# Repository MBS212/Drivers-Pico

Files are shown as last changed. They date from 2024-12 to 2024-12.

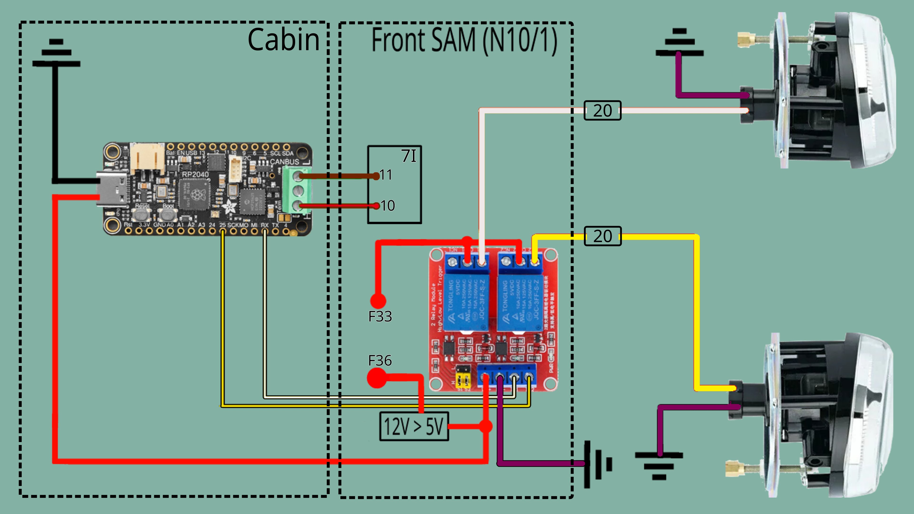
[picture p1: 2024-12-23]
Images/Electrical-diagram.jpg

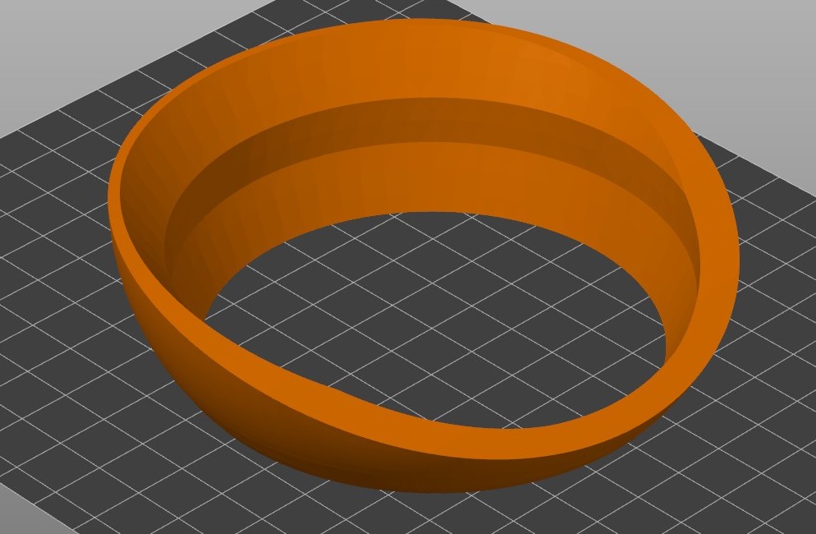
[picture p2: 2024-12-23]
Images/light-unit-bezel.jpg

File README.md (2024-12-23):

This is the repo for fitting Adafurit RP2040 CAN bus Feather to Mercedes-Benz W/S 212 vehicles as additional controller and plugging it into the vehicle's CAN bus B, to interract with other control units.

Currently implemented the following functions:
  1. Fitting custom cornering lights to Mercedes-Benz vehicle, model S212 by aquiring CAN bus messges. The code was created in Arduino IDE. The CAN bus IDs used in this project so far:
     1. Steering Angle Sensor;
     2. Light Sensor;
     3. Turn Indicator switch msgs;
     4. Vehicle Speed Sensors;
     5. Vehicle's Headlight Sensor.

For the full explanation see the following YouTube videos:
1. Video 1 - short demo, needed hardware, and sniffing thrugh the CAN bus frames: https://youtu.be/QOX_SNWhKeo
2. Video 2 - Analizing the Arduino Code: https://youtu.be/sk0XZvBpJHA
3. Video 3 - Installing of the hardware: https://youtu.be/rINvdyTEydw

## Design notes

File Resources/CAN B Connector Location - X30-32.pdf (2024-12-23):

Document title | Location of electrical connectors - Left front footwell
Document number | gf0019p100512dda

# 1005-12DDA Location of electrical connectors - Left front GF00.19-Pfootwell

# Model 213 as of model year 2021

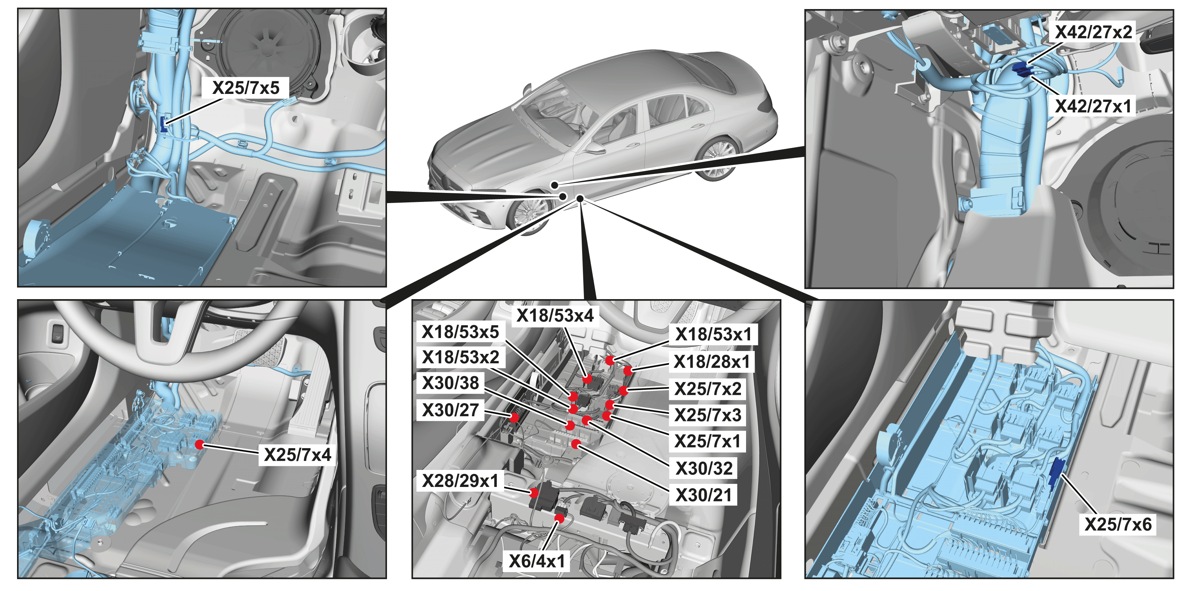
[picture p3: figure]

P54.18-A138-79

© Mercedes-Benz AG, 2/27/23, L/10/20, gf00.19-p-1005-12dda, Location of electrical connectors - Left front footwell | Page 1 of 1
Model 213 as of model year 2021

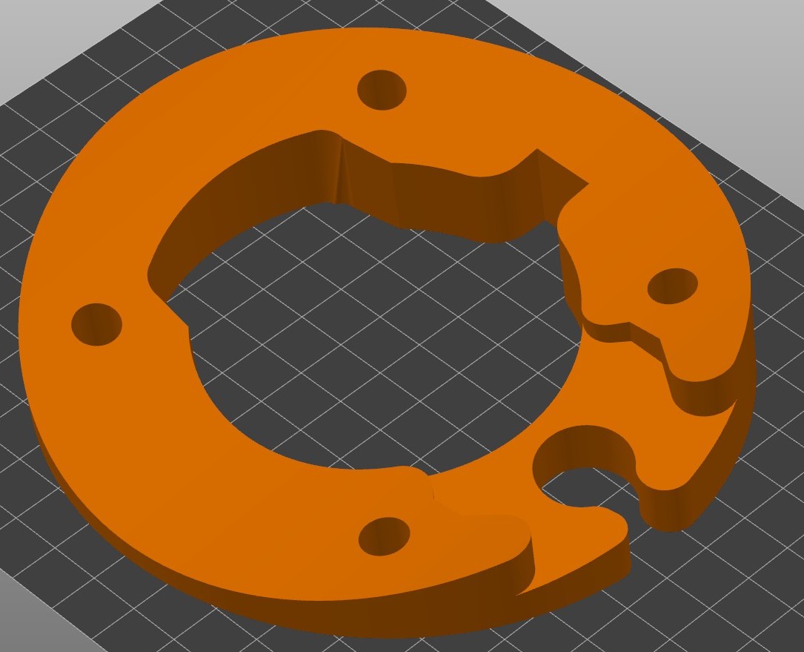
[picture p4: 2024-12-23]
Images/light-unit-bracket(flange)-rear-Right.jpg

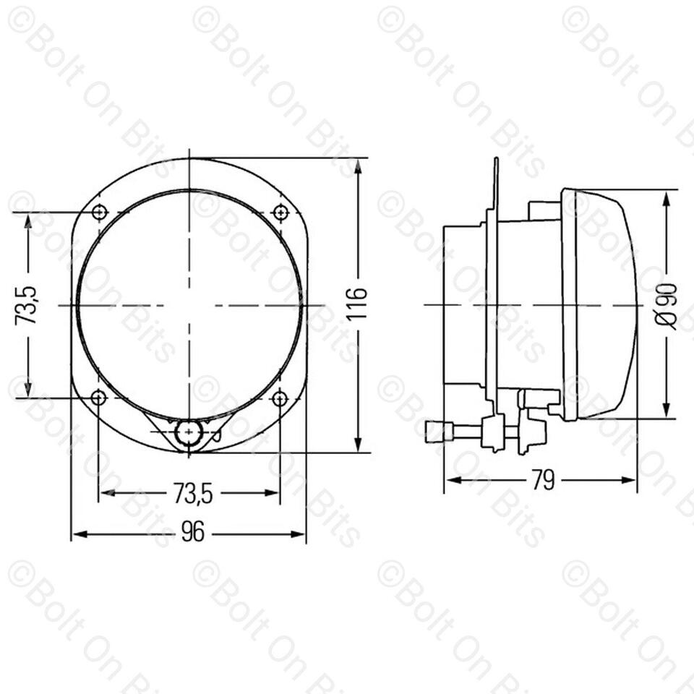
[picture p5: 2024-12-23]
Images/merc-cornering-lights-dimensions.jpg

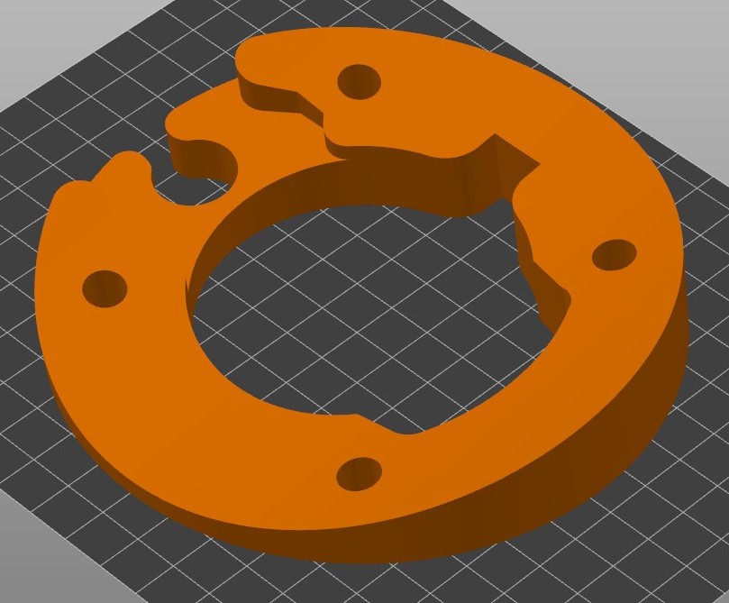
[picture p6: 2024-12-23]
Images/light-unit-bracket(flange)-rear-Left.jpg

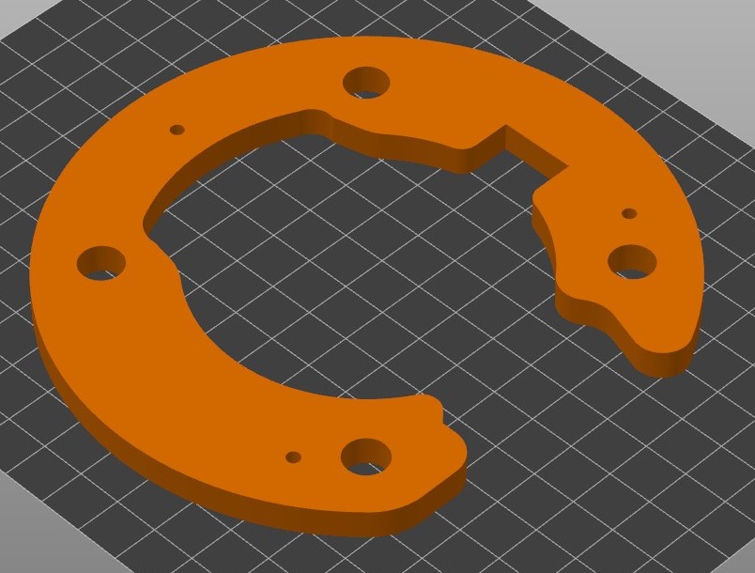
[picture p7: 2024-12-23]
Images/light-unit-bracket-front-L-and-R.jpg

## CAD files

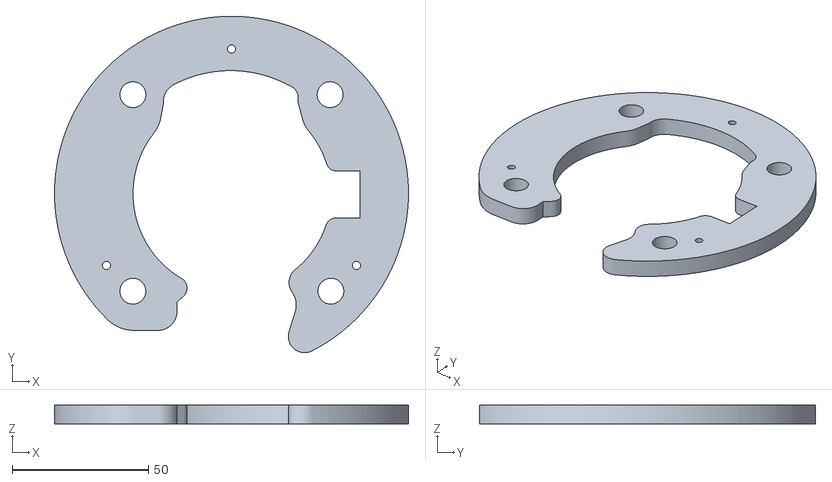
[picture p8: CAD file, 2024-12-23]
STL Files/light-unit-bracket-front-L-and-R.stl
130.0 x 123.5 x 6.82

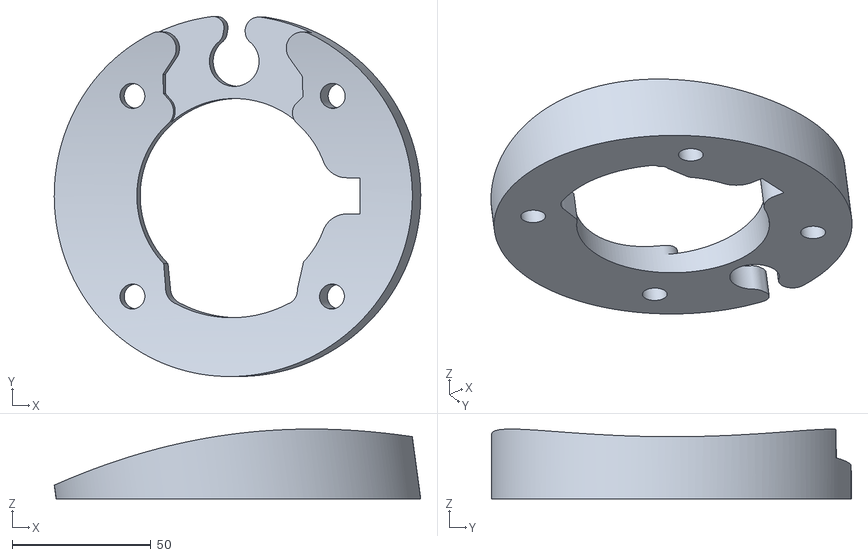
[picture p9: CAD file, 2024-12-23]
STL Files/light-unit-bracket(flange)-rear-Left.stl
131.9 x 129.5 x 25.2

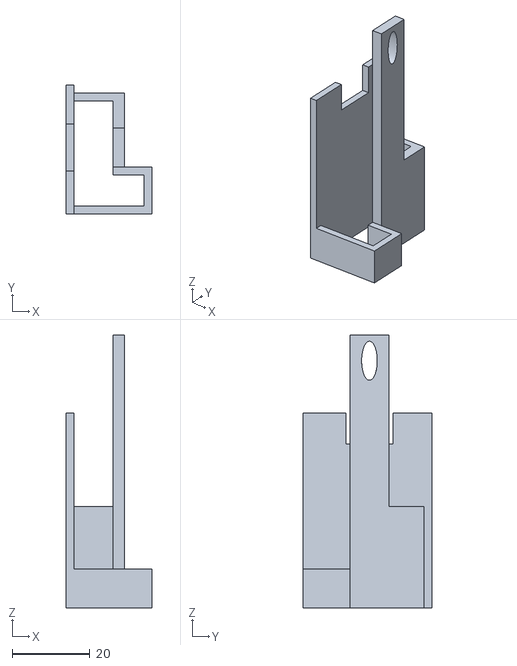
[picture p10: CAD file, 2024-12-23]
STL Files/pico-enclosure.stl
22.0 x 33.0 x 70.0

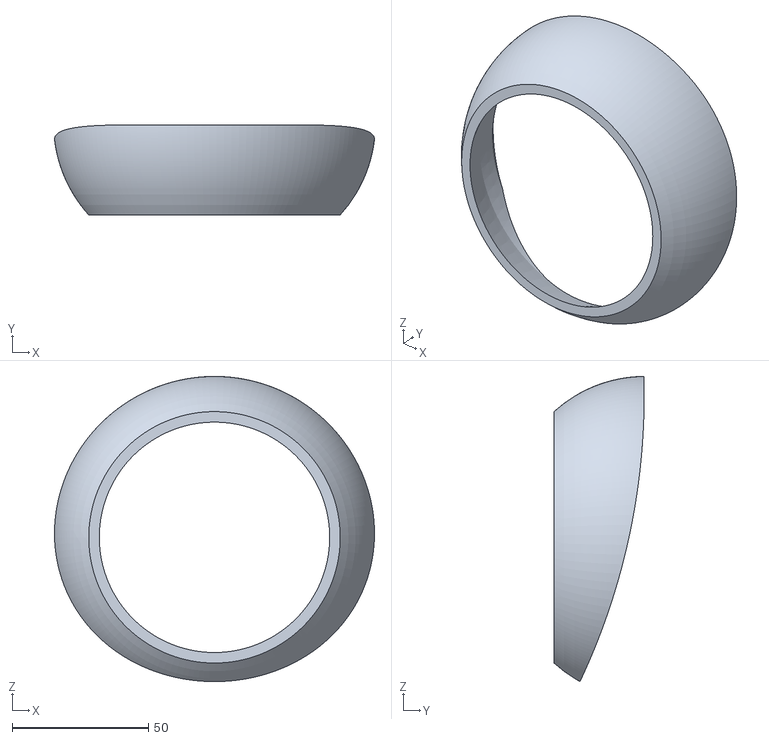
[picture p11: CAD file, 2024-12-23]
STL Files/light-unit-bezel.stl
117.2 x 33.0 x 111.8

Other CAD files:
STL Files/light-unit-bracket(flange)-rear-Right.stl

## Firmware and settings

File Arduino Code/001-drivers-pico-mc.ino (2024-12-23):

// main file of the project to:
// - to switch on/off the custom cornering lights;
// - to move servo with my GoPro camera attached to it;
// based on the Mercedes S212 E300 Hybrid, 
//   the sensor data aquired through the CAN bus frames

#include "canbusreader.h"  // file to process CAN bus messages and get the values
#include "servocontrol.h"  // file to control GoPro servo motor dep. on st. wheel angle
#include "corneringlights.h"  // to control the cornering lights

bool Debug = false;  // onboard neopix is OFF, set to true for debugging

// trying to smooth servo movements with millis()
unsigned long canTime = 0;
unsigned long servoTime = 0;
unsigned long pixelsTime = 0;

void setup()  // rp2040 1st core setup
{
  SetupCan();     // defined in canfunctions.h
  delay(1000);
}

void loop()  // rp2040 1st core loop
{
  // process CAN bus msgs and return the steering wheel angle (value betw. 3100 & 5100)
  // this function is in canbusreader.h
//  if( millis() - canTime >= 5 )
//  {
    ReadCAN();  
//    canTime = millis();
//  }
}

///////////////////////////////////////
void setup1()  // rp2040 2nd core setup
{
  SetupServo();   // defined in servocontrol.h

  SetupCorneringLights();

  // Set the on-board Neopixel pin to output and high
  //   in order to enable the NeoPixels. 
  if( Debug )
  {
    pinMode(NEOPIXEL_POWER, OUTPUT);
    digitalWrite(NEOPIXEL_POWER, HIGH);
    pixels.begin();            // init. NeoPixel object
    pixels.setBrightness(5);  // NeoPixel's brightness
  }
  delay(1000);
}

void loop1()  // rp2040 2nd core loop
{
  // if it's daylight,
  // than move our GoPro's servo depending on
  // the st. wheel angle, 
  // else we don't need to control servo at night
  if( !nightTime )
  {
    if( millis() - servoTime >= 10 )
    {
//      MoveGopro();  // this function is in servocontrol.h
      servoTime = millis();
    }
  }

  // 29.04.2024:
  //   Removed frome here the condition if(nightTime)
  //   because it would create a bug that it will not switch off the lights 
  //   when nightTime changes to false (day time) while we are driving.
  //   This condition is now added in the RunCorneringLights() function.
  RunCorneringLights();

  if( Debug )
  {
    if( millis() - pixelsTime >= 100 )
    {
      pixels.fill(currentPixColor); // set the pix color
      pixels.show();                // light up the pix
      pixelsTime = millis();
    }
  }
}

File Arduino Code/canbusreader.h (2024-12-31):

/* contains functions:
SetupCan()
ReadCan() to read the can bus
          and to process the data
          
updates:
28.12.24 - added reading of the 3rd byte from CAN msg because
           the 3rd byte of turn signal give clear indication
           if left is on, or if right is on;
         - changed turn signal values from 80 and 144 to 5 and 10 from the 3rd byte
           so that the event will trigger not only on touch, but also on switch
         - added gearLeverPos var., in order to switch on both corn. lights 
           not when the vehicle starts moving backward, but when the reverse gear
           is engaged with the gear lever (right side of steer. wheel) 
*/
#include <Adafruit_MCP2515.h>

#define CS_PIN    PIN_CAN_CS
Adafruit_MCP2515 mcp(CS_PIN);  // the CAN bus processing
  
// Set CAN bus baud rate depending on which CAN bus we are connected to
#define CAN_B   125000  // bus B speed: 125 kbps
#define CAN_E   500000  // bus E speed: 500 kbps

// variables related to reading the vehicle's light sensor
uint8_t lightSensorId = 37;       // light sensor messages id (00025 in hex)
uint8_t lightSensorMaxVal = 199;  // the darker outside the higher the value - needs fine tuning
bool nightTime = false;           // remember if it's light or dark

// variable to process lights messages
int16_t headlightsId = 105;  // vehicle lights msg. id (00069 in hex),
uint8_t headlightsVal = 12;  // 0x0C in hex, the value that we need has to be above 4
                             //   only first Byte changing with the switch, as follows:
                             //   no lights - 0, side lights - 4 (0x04), auto - 76(0x4C), low beam - 12 (0x0C)
char headlights = 'N';       // remember the state of the headlights [N-none, S-side, L-low beam]

// variables to process speed messages
uint16_t speedId = 515;     // vehicle speed msg id (00203 in hex)
uint16_t currentSpeed = 0;  // remember the last CAN speed value
uint8_t speedDirection = 4; // remeber the dir. of travel, 4 - forward, 8 - reverse

// variables to process Gear Lever frames id: 109 (6D hex)
uint16_t gearLeverId = 109;  // gear lever id
uint8_t gearLeverPos = '0';  // remember the last position of the gear lever

// variables to process the turn signal messages
int16_t turnSignalId = 41;    // turn indicator L & R msg id (00029 in hex big-endian),
                                 //   1st byte shows if we have touch or switchs or emerg. as follows:
                                 //   no indicators: 00 00, left touch: 80, left switch on: 64,
                                 //     right touch: 144, right switch on: 128
                                 //   3rd byte shows if we have left or right, no matter if it's switch or touch
uint8_t turnSignalLeft = 5;     // left on (switch or touch) 05 in hex
uint8_t turnSignalRight = 10;   // right on (switch or touch) 0A in hex
char turnSignal = 'N';           // none of the turn signals is blinking

// variables to process the steering angle messages
int16_t  stAngleId = 3;    // steering angle msg id (00003 in hex)
uint16_t stAngleVal = 4096;  // this will hold the first 2 Bytes of data from the steering angle sensor's msg
                                 //   and it will also be used to control the GoPro servo movement in (see servocontrol.h)



////////////////////////////
// declaration of the function in this file
void ReadLightSensor(uint8_t byte1);            // find out if it's day or night time
void ReadHeadlights(uint8_t byte1);             // read & save current state of the headlights
void ReadSpeed(uint8_t byte1, uint8_t byte2);   // read & save current speed
void ReadGearLever(uint8_t byte2);   // read the gear lever values (right on steer. wheel)
void ReadTurnSignal(uint8_t byte3);             // find out if the turn indic. is on and which one
//////////////////////////////////////////////////////////////////////////////
                                
// this func. is called from the main setup() function in the 001-steering (our main) file
void SetupCan() 
{
//Serial.begin(115200);
  if( ! mcp.begin(CAN_B) )  { while(1); } 
}


// the main and only function in this file - to read and process CAN msgs
//   and in the second part to switch our cornering lights on/off
void ReadCAN()
{
  uint16_t canMsgId = 0; // current message ID
  uint8_t a = 0;  // 1st byte from CAN msg data
  uint8_t aa = 0; // 2nd byte from CAN msg data
  uint8_t aaa = 0; // 3rd byte from CAN msg data

  int packetSize = mcp.parsePacket();

  if( packetSize )  // if CAN frame is detected, otherwise skip to the end of the func and repeat again
  {
    canMsgId = (uint16_t) mcp.packetId();  // read the CAN msg ID

    if( mcp.available() )      // if the msg data Bytes are avail., or skip to the end and cycle again
    {                          //     in any of the 5 frames that we need, only the 1st 2B of the msg data is usefull to us, so:
      a = mcp.read();          // read 1st byte from the msg data field
      aa = mcp.read();         // read 2nd byte from the msg data field
      aaa = mcp.read();        // read 3rd byte from the msg data field
    }
    else
    {
      return; 
    }
       // check for the steering angle messages 
    if( canMsgId == stAngleId )   // 3 in decimal and in hex
    {
      stAngleVal = (a<<8) + (aa<<0);   // move a into the 1st Byte, aa into the 2nd, of the stAngleVal
        //Serial.print("st angle:"); Serial.print(stAngleVal);  // for debuging
    }
       //  look for light sensor msg. and receord its value
    else if( canMsgId == lightSensorId )  // 37 decimal
    {
      ReadLightSensor(a);
    }
//  check for the headlights messages and call the function to get the values
//  01.12.24 - enabled reading of the headlights to be able to switch off
//             cornering lights together with headlights if needed
//             also added the condition in the RunCorneringLights() in corneringlights.h
    else if( canMsgId == headlightsId )  // 105 decimal
    {
      ReadHeadlights(a);
    }
    else
    {
      // just ignore
    }
    // read & process CAN bus msgs further only if it's night time,
    if( nightTime )  // headlightsOn && nightTime )
    { 
      if( canMsgId == gearLeverId )    // check if new speed msg (with id 515) was sent
      {
        ReadGearLever(aa);  // 1st byte always 64(40 hex), so need only byte2
      }
      if( canMsgId == speedId )    // check if new speed msg (with id 515) was sent
      {
        ReadSpeed(a, aa);
      }
      if( canMsgId == turnSignalId )     // check if turn indicator was triggered
      {
        ReadTurnSignal(aaa);
      }
    }  // end of if headlights ON condition 
  }  // end of frame detection
}
/////////////////////////////////////
// functions defs. used above in this file
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

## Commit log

2024-04-17 Mercedes E350 year 2010 partial DBC
    This is the DBC file with some CAN bus data from the Mercedes E 350, year 2010.
2024-04-27 Add files via upload
    drivers-pico Arduino project files that are to be used with Adafruit RP2040 CAN Bus Feather.
2024-12-23 Add files via upload
    The .stl files for printing
    [light-unit-bezel.stl, light-unit-bracket(flange)-rear-Left.stl, light-unit-bracket(flange)-rear-Right.stl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]
